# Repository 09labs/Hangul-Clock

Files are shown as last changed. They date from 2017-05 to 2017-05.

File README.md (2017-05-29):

# Hangul Clock

한글시계 프로젝트입니다. 단국대학교 학술동아리 연구방에서 지원받아 제작한 프로젝트입니다.

한글날이 한참 멀었지만, 한글날을 대비하기 위하여 제작하였습니다.

아트웍, MDF재단, 소스코딩까지 2주밖에 안걸린 굇수라 죄송합니다.

프로젝트 참여자 - 김승권(팀장), 유정훈, 황주원, 차동준

V 1.0 - 기존 한글시계에서 버튼을 추가하여 색을 변경하는 기능을 추가하였습니다. RGB 각각 12단계로 조절이 가능합니다.

English

Korean(Hangul) Clock Project. 09room is electrical and electronic community. 09room supported this project.

Project Manager - Seung Gwon, Kim

Project Member - Jeong Hoon, You / Joowon, Hwang / Dong Joon, Cha

V 1.0 - Originally Hangul clock has a function that display time. But i added a button. 

So you can change a color R, G, B 12 levels.

made by Seung Gwon, Kim

# 아두이노 필수 라이브러리 설치

아두이노 IDE설치 후 DS1302 리이브러리(Henning Karlsen)와 Thread 라이브러리, Adafruit NeoPixel 라이브러리를 추가합니다.

DS1302 - http://www.rinkydinkelectronics.com/library.php?id=5

Thread - 아두이노IDE -> 스케치  -> 라이브러리 포함하기 -> 라이브러리 관리 -> Thread 검색 후 추가

Adafruit NeoPixel - https://github.com/adafruit/Adafruit_NeoPixel

Github에서 다운받으신 압축파일은 아두이노 IDE - 스케치 - 라이브러리 포함하기 - .ZIP 라이브러리 추가 기능을 사용하시면 됩니다.

# 아두이노 함수 설명

hourChange(hours, minutes) - hours와 minutes에 따라 '시'에 해당하는 네오픽셀을 변경합니다.

minuteChange(minutes) - minutes에 따라 '분'에 해당하는 네오픽셀을 변경합니다.

resetLED() - 1분에 한 번씩 호출하는 함수로 네오픽셀을 전부 초기화합니다.

setTimee(input) - input은 String type으로 "12:23:33"과 같은 형태로 구성된 문자열에서
시, 분, 초를 분리하여 클래스 private 변수에 값을 저장합니다.

blinkSec() - 1초에 한번씩 '초'에 해당하는 네오픽셀을 점멸시킵니다. 전체 주기는 2초입니다.

AMPM(uint8_t hours) - hours의 값에 따라서 오전, 오후 값을 바꿔 표기합니다.

updateTime() - 시간을 갱신시킵니다.

# PCB 주문방법

Gerber 폴더에 있는 파일을 PCB 주문제작업체에 보내면 알아서 해줍니다.

## * 부품리스트

  * Arduino Nano - 1EA (http://storefarm.naver.com/ic11401/products/650416459)
  * USB Micro breakout board - 1EA (https://goo.gl/hY34n9)
  * DS1302 - 1EA (http://storefarm.naver.com/ic11401/products/646964977)

  * WS2812 - 36EA (http://goo.gl/elRKqF) 꼭 4핀짜리로 구매할 것
  * 네오픽셀 Strip - LED 간격이 1.65cm인 것을 선택할 것 (http://www.devicemart.co.kr/1328620)

  * WS2812와 네오픽셀 스트립 중 하나만 구입하면 됩니다!

  * 0805 Ceramic Capacitor 100nF - 36EA (http://www.devicemart.co.kr/8191)
  * 0805 Chip resistor 10K ohm - 3EA (http://www.devicemart.co.kr/19263)
  * 12x12mm Tact switch - 3EA (http://www.devicemart.co.kr/35853)
  * Pin Header Socket 2.54mm 1x15 Straight - 2EA (http://www.devicemart.co.kr/12497)
  * Pin Header Socket 2.54mm 1x5 Straight - 2EA (http://www.devicemart.co.kr/12494)
  * Molex 5045 3pin - 1EA (http://www.devicemart.co.kr/462)
  * Molex 5051 3pin - 1EA (http://www.devicemart.co.kr/501)
  * Molex 5051 crimp - 3EA (http://www.devicemart.co.kr/5464)

  * 업체로부터 지원을 받아 제작한 글이 아님을 알려드립니다.

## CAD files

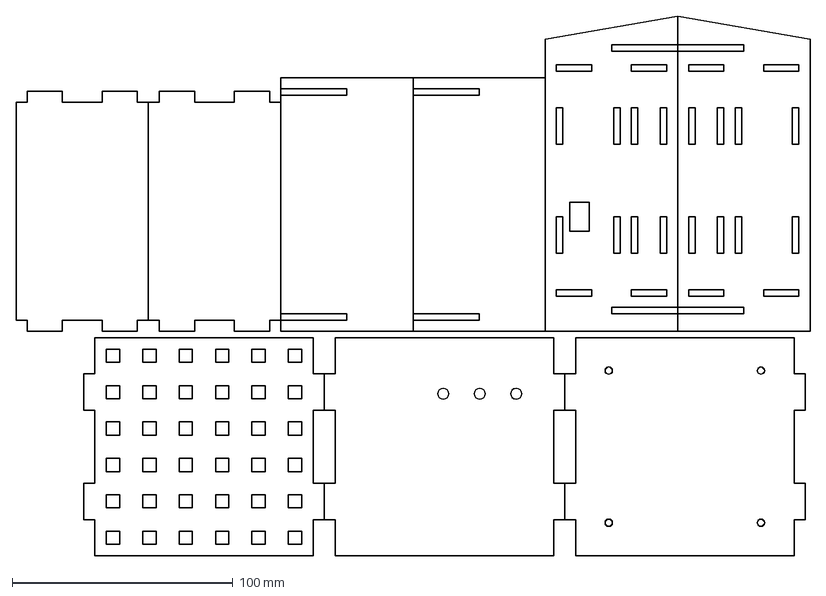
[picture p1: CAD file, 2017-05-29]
DXF_FILES/RealFinal_DXF.dxf
360.0 x 244.7 mm

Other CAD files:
DXF_FILES/RealFinal_DXF.dwg

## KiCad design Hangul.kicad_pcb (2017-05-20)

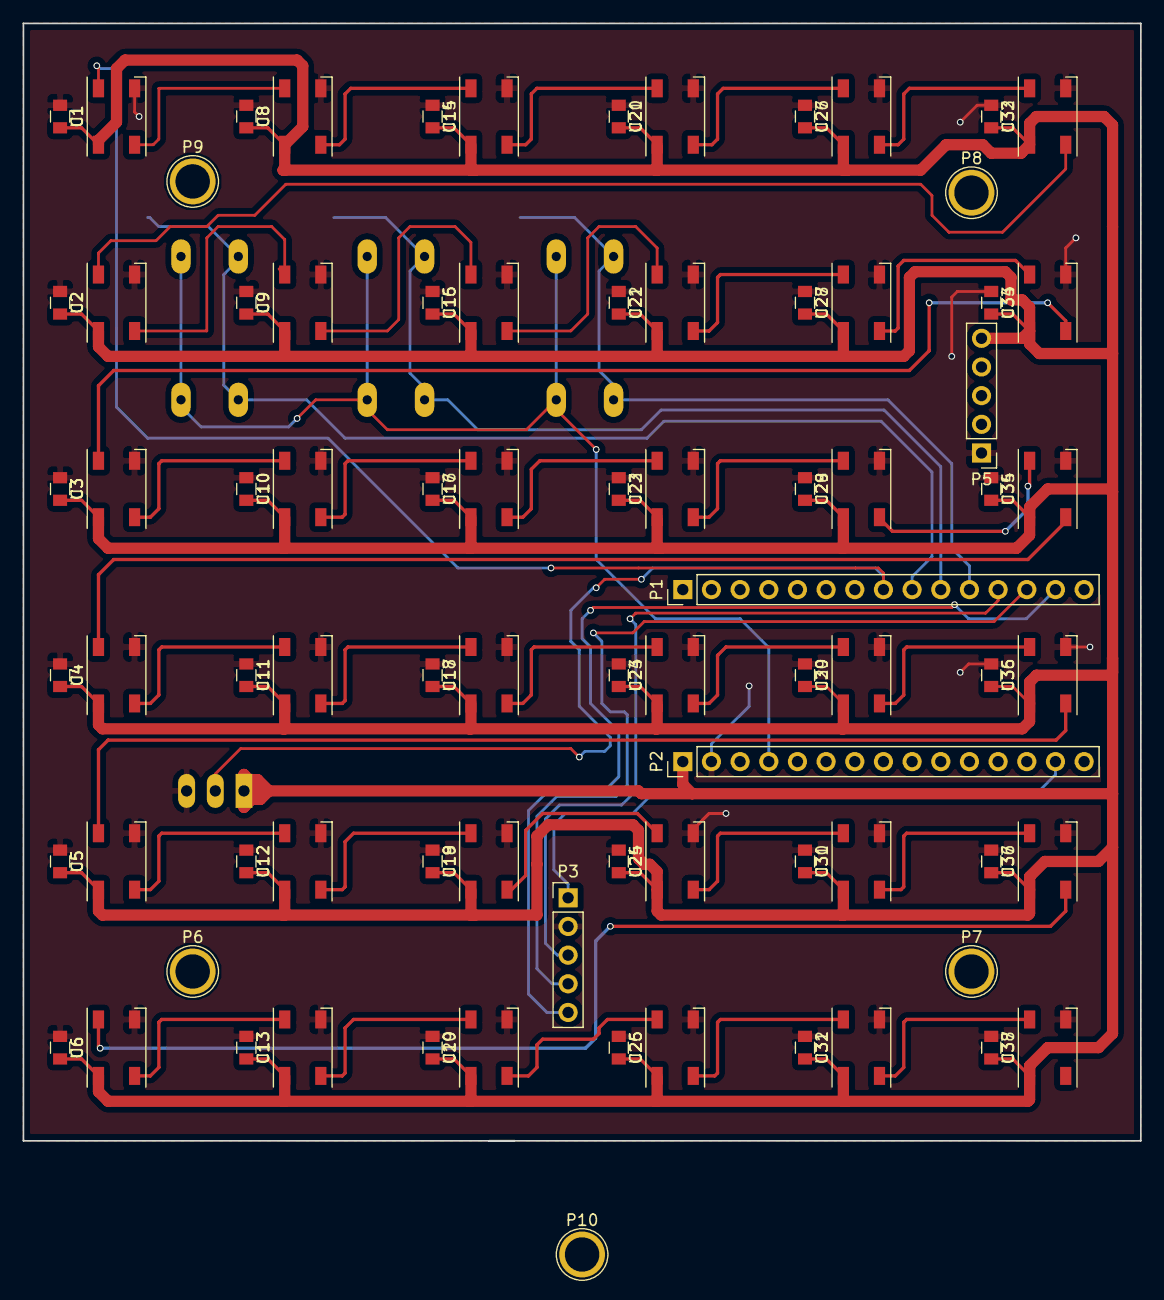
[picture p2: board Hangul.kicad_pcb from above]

Board: 2 copper layers, 99.0 x 99.0 mm, 88 parts (0 on the bottom side), 46 nets.

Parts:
C1, C2, C3, C4, C5, C6, C8, C9, C10, C11, C12, C13, C15, C16, C17, C18, C19, C20, C21, C22, C23, C24, C25, C26, C27, C28, C29, C30, C31, C32, C33, C34, C35, C36, C37, C38: C; C_0805
P1: NANO_1; Pin_Header_Straight_1x15_Pitch2.54mm
P2: NANO_2; Pin_Header_Straight_1x15_Pitch2.54mm
P3: DS1302; Pin_Header_Straight_1x05_Pitch2.54mm
P4: CONN_01X03; MOLEX-5045-03A
P5: POWER; Pin_Header_Straight_1x05_Pitch2.54mm
P6, P7, P8, P9: S; 1pin
P10: s; 1pin
R1, R2, R3: R; R_0805BCU
SW1: SW_R; SW_PUSH-12mmBCU
SW2: SW_G; SW_PUSH-12mmBCU
SW3: SW_B; SW_PUSH-12mmBCU
U1, U2, U3, U4, U5, U6, U8, U9, U10, U11, U12, U13, U14, U15, U16, U17, U18, U19, U20, U21, U22, U23, U24, U25, U26, U27, U28, U29, U30, U31, U32, U33, U34, U35, U36, U37: WS2812B; LED_WS2812B-PLCC4

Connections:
+5V: P2.4, SW1.1, SW2.1, SW3.1
+5VA: C1.2, C2.2, C3.2, C4.2, C5.2, C6.2, C8.2, C9.2, C10.2, C11.2, C12.2, C13.2, C15.2, C16.2, C17.2, C18.2, C19.2, C20.2, C21.2, C22.2, C23.2, C24.2, C25.2, C26.2, C27.2, C28.2, C29.2, C30.2, C31.2, C32.2, C33.2, C34.2, C35.2, C36.2, C37.2, C38.2, P2.1, P4.1, P5.5, U1.1, U2.1, U3.1, U4.1, U5.1, U6.1, U8.1, U9.1, U10.1, U11.1, U12.1, U13.1, U14.1, U15.1, U16.1, U17.1, U18.1, U19.1, U20.1, U21.1, U22.1, U23.1, U24.1, U25.1, U26.1, U27.1, U28.1, U29.1, U30.1, U31.1, U32.1, U33.1, U34.1, U35.1, U36.1, U37.1
CLK: P1.12, P3.3
DAT: P1.13, P3.4
DIN: P1.8, P4.2, U1.4
GND: C1.1, C2.1, C3.1, C4.1, C5.1, C6.1, C8.1, C9.1, C10.1, C11.1, C12.1, C13.1, C15.1, C16.1, C17.1, C18.1, C19.1, C20.1, C21.1, C22.1, C23.1, C24.1, C25.1, C26.1, C27.1, C28.1, C29.1, C30.1, C31.1, C32.1, C33.1, C34.1, C35.1, C36.1, C37.1, C38.1, P1.4, P2.2, P3.2, P4.3, P5.1, R1.1, R2.1, R3.1, U1.3, U2.3, U3.3, U4.3, U5.3, U6.3, U8.3, U9.3, U10.3, U11.3, U12.3, U13.3, U14.3, U15.3, U16.3, U17.3, U18.3, U19.3, U20.3, U21.3, U22.3, U23.3, U24.3, U25.3, U26.3, U27.3, U28.3, U29.3, U30.3, U31.3, U32.3, U33.3, U34.3, U35.3, U36.3, U37.3
unnamed: P1.9, R1.2, SW1.2
unnamed: P1.10, R2.2, SW2.2
unnamed: P1.11, R3.2, SW3.2
unnamed: P2.14, P3.1
unnamed: U1.2, U8.4
unnamed: U2.2, U9.4
unnamed: U2.4, U32.2
unnamed: U3.4, U33.2
unnamed: U10.2, U16.4
unnamed: U3.2, U10.4
unnamed: U11.2, U17.4
unnamed: U4.2, U11.4
unnamed: U12.2, U18.4
unnamed: U5.2, U12.4
unnamed: U13.2, U19.4
unnamed: U6.2, U13.4
unnamed: U14.2, U20.4
unnamed: U8.2, U14.4
unnamed: U15.2, U21.4
unnamed: U9.2, U15.4
unnamed: U16.2, U22.4
unnamed: U17.2, U23.4
unnamed: U18.2, U24.4
unnamed: U19.2, U25.4
unnamed: U20.2, U26.4
unnamed: U21.2, U27.4
unnamed: U22.2, U28.4
unnamed: U23.2, U29.4
unnamed: U24.2, U30.4
unnamed: U25.2, U31.4
unnamed: U26.2, U32.4
unnamed: U27.2, U33.4
unnamed: U28.2, U34.4
unnamed: U29.2, U35.4
unnamed: U30.2, U36.4
unnamed: U31.2, U37.4
unnamed: U4.4, U34.2
unnamed: U5.4, U35.2
unnamed: U6.4, U36.2
RST: P1.14, P3.5

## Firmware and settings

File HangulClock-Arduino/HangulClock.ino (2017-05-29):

#include "Hangul.h"
#include <DS1302.h>
#include <Thread.h>
#ifdef __AVR__
  #include <avr/power.h>
#endif
#define PIN 5
#define NUMPIXELS 36
Thread myThread = Thread();
DS1302 rtc(11,10,9);
Hangul hangul(PIN, NUMPIXELS);

String tim="";
uint8_t flag = 0;
String d, t;
struct timerr{
  int years;
  int months;
  int days;
  int hours;
  int mins;
  int secs;
};
timerr TT;
void callBack(){
  tim = rtc.getTimeStr();
  hangul.blinkSec();
  Serial.println(tim);
  }
void setup() {
  myThread.onRun(callBack);
  myThread.setInterval(1000);
  pinMode(6,INPUT);
  pinMode(7,INPUT);
  pinMode(8,INPUT);
  #if defined (__AVR_ATtiny85__)
    if (F_CPU == 16000000) clock_prescale_set(clock_div_1);
  #endif

  d = __DATE__;
  t = __TIME__;
  
  hangul.pixels.begin();
  

  int d_first = d.indexOf(" ");
  int d_seconds = d.indexOf(" ", d_first+1);
  int t_first = t.indexOf(":");
  int t_seconds = t.indexOf(":",t_first+1);
  
  TT.months = d.substring(0,d_first).toInt();
  TT.days = d.substring(d_first+1, d_seconds).toInt();
  TT.years = d.substring(d_seconds+1).toInt();
  TT.hours = t.substring(0,t_first).toInt();
  TT.mins = t.substring(t_first+1,t_seconds).toInt();
  TT.secs = t.substring(t_seconds+1).toInt();
  
   
  // Setup Serial connection
  Serial.begin(9600);
  //rtc.halt(false);
  //rtc.writeProtect(false);   
  //rtc.setDOW(FRIDAY);
  //rtc.setDate(TT.days, TT.months, TT.years);
  //rtc.setTime(TT.hours, TT.mins, TT.secs);
  /*
  RTC에 해당하는 주석을 모두 해제할 경우 RTC모듈에 시간이 기록됩니다
  요일을 설정하고 싶으면 setDOW안의 단어를 변경하세요.
  주석을해제한뒤업로드하면DS1302에시간이기록됩니다
  시리얼 모니터를 켜서 시간을 확인한 뒤에는 반드시 RTC에 해당하는 부분의 주석처리를 다시 한 뒤 업로드를 해주셔야 정상 작동합니다
  */
  hangul.resetLED();
}

void loop() {
  // 시:분:초  다음과 같은 형식으로 입력하면 시간이 입력됩니다
  // start라고 입력하면 타이머가 시작됩니다

  if(myThread.shouldRun()){
    myThread.run();
  }
  hangul.setTimee(tim);

  hangul.updateTime();
  hangul.colorChange(); 
  
  // put your main code here, to run repeatedly:
  //delay(1000);
}

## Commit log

2017-05-20 Schematic
    Korean Clock schematic diagram
    [Hangul.sch]
2017-05-20 PCB
    Korean clock PCB
    [Hangul.kicad_pcb]
2017-05-20 KiCAD Project file
    KiCAD Project file
2017-05-29 한글 출력부 DXF/AI Files
    [RealFinal_DXF.dwg, RealFinal_DXF.dxf]
2017-05-29 MDF 재단파일
2017-05-29 PCB BackupFile
2017-05-29 한글시계 MDF 재단 / Hangul Clock Laser Cutting Files
    [RealFinal_DXF.dwg, RealFinal_DXF.dxf]
